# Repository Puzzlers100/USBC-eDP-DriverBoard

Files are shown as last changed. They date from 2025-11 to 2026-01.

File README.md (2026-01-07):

## __USBC-eDP Driver Board__  

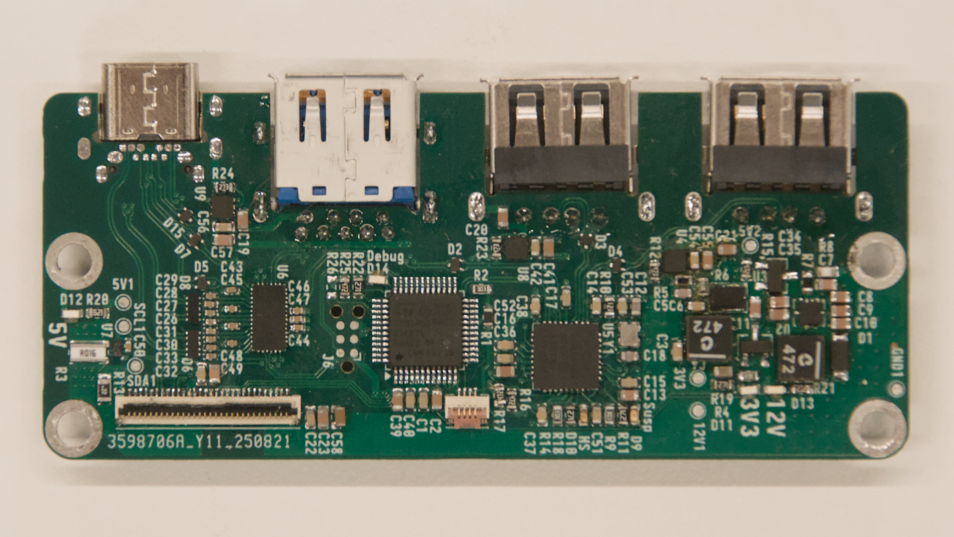
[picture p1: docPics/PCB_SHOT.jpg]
Soldered embedded displayport adapter

This project works to adapt a USB-C DisplayPort alt-mode input into an embedded DisplayPort output. It uses an STM32 to communicate over the USB-C Power delivery protocol, acts as a USB Hub providing one USB 3.0 Superspeed port and 2 USB 2.0 High Speed ports. It also negotiates the highest current available from the source, and internally generates the 12V needed to run the display.  It works by simply routing the same DP signals through to the output, and does no signal processing of it's own. 
## USE  

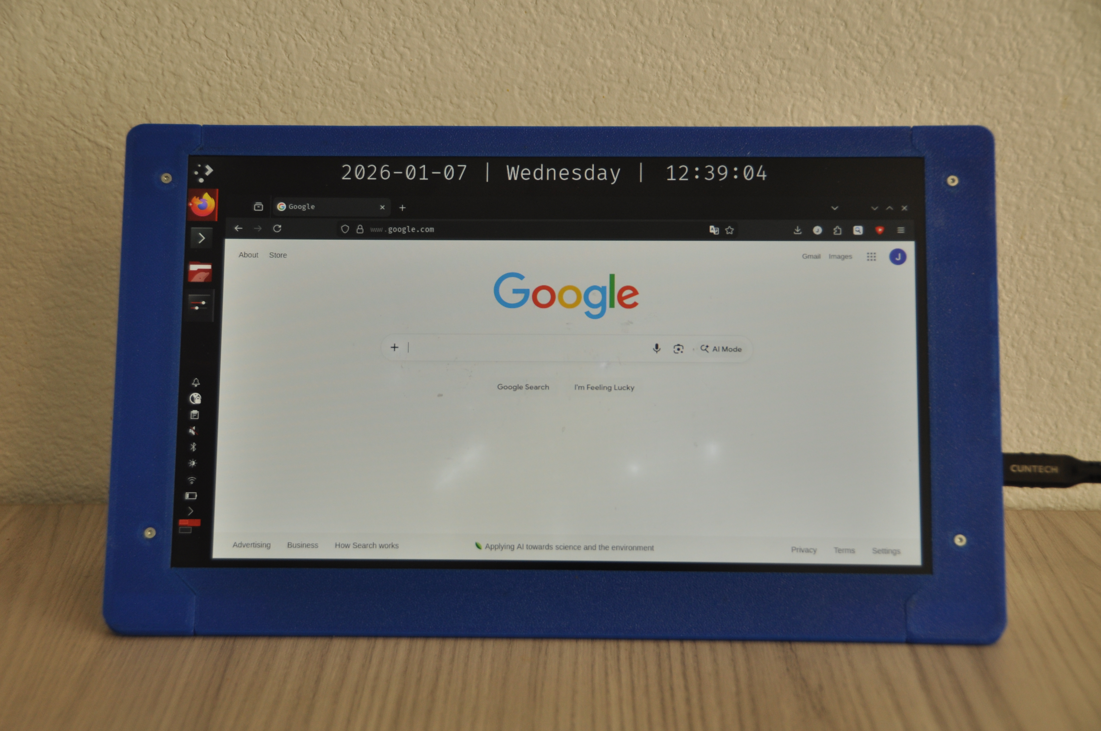
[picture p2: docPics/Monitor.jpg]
Portable monitor built using this driver board


It should work with most 30pin eDP panels. Since it has no native processing on it's own, the DP generation is set by the computer and panel used. Generally, this allows for up to 1080p panels. Exceptionally large or exceptionally bright panels may not work, as those panels tend to draw a large current on the 12V rail. I highly recommend sticking to panels that draw a continuous current of no more than 800mA for the backlight.

The STM32 provides PWM dimming capability by using the potentiometer on the daughter board. If you want to remove this capability, short pin 1 to pin 2 on J2 (This is a temporary solution, the plan is to in the future specify which brightness control scheme should be used using R25 and R26)

Personally, I am using the Innolux N116BCA-EA1 panel with a 3D printed case published in the Mechanical folder. If you would prefer a 1080p panel, the AUO G116HAN looks like it should also fit the case, however I do not have one to test with. 

#### NOTICE
The USB 2.0 ports are configured to run outside of the USB specification. They claim to be able to provide up to 500mA of current, however trigger overcurrent protection at 250mA. This can be fixed by replacing line 17 in i2C_comms.c with {0x18, 0x20, 0x01}, however the incorrect version can be useful with higher power flash drives that require 200mA, which was the reason I chose to do it this way.
## BUILD INFO

#### PCBs
BOMs for both the main board and secondary board are in the electrical folder, and contain all the parts required to build a fully functional PCB.  The main board is specifically designed to be manufactured using JLC-PCBs JLC04081H-3313 stackup, as the USB lines are impedance matched, and the generated gerber files are designed to be used with JLC. The potentiometer board has no such restrictions, but I recommend using a 0.8mm PCB. Currently there is no pick and place support, so you will need to hand solder the PCBs. The passives should be rated for at least 12V

## Firmware
The firmware is written using the STMCube Ide. To get the PCB to work, you need to compile it using cube IDE, then upload it to the STM32 using either a J-link or STlink. If you have a TagConnect TC2030, there is a pad connector available on the PCB, if not, the pads are big enough you could solder on some leads to them.

## FFC cables
The design uses a Type A, 4pin, 0.5mm pitch FFC cable to connect the main board and pot board. For my design, I used a 10cm long cable, though what length you need may depend on your chosen LCD and layout

You will also require a 30 pin eDP cable. I used a 250mm one for my design.

## Hardware
The mechanical design is published as a set of solidworks files as well as a set of 3MFs. The 3MFs were made for the Prusa MK3S+ with the MMU2, though they will likely work with most slicers and printers that support multi filament printing. They are designed to be printed in PETG with appropriate scaling to account for shrinkage. A couple of the parts also have support blocks with a PLA interface so they should be removable. 

To fully assemble the enclosure, you will need:

- 19x [M2 4.8mm Wide, 1.5mm thick nuts](https://www.mcmaster.com/92513A110/)
- 13x [M2 10mm Countersunk Screw](https://www.mcmaster.com/90236A106/)
- 17x [M2 6mm Countersunk Screw](https://www.mcmaster.com/90236A104/)
- 13x [M2 4mm Countersunk Screw](https://www.mcmaster.com/90236A102/) 
	
## TODO
Future Plans are mostly in the software:
 - USB HID interface for brightness control and notifications
 - Proper current monitoring and active over-current protection control by reducing screen brightness
 - Use R25 and R26 resistors to define which brightness control method is desired.
 - Redesign the enclosure to use metal nuts. I just used some nuts I had on hand that I thought were M2 but are actually probably M2.5

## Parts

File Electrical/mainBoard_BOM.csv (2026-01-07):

Id | Designator | Footprint | Quantity | Designation | Manufacturer | Ref
1 | C1,C39,C38,C16,C51,C55,C14,C41,C17,C52,C24,C53,C57,C6,C22,C37,C15 | 0603_C | 17 | 100n
2 | C25,C11,C54,C23,C35,C42,C2,C56,C8,C13,C19,C21,C9,C36,C7,C40,C34,C10,C20 | 0603_C | 19 | 10u
3 | J2 | FH19C-4S-0.5SH(10) | 1 | 4_Pin_Zif | Hirose | FH19C-4S-0.5SH(10)
4 | Q2 | TSOT-23 | 1 | NPN | onsemi | NSS40201LT1G
5 | R9,R6,R4,R14 | 0603_R | 4 | 30K
6 | D13,D12,D9,D11,D10,D14 | LTST_Diode | 6 | LED | LITE-ON | S270GTK
7 | C44,C47,C43,C50,C46,C45,C49,C48 | 0402_C | 8 | 100n
8 | C58 | 0603_C | 1 | 22u
9 | R5 | 0603_R | 1 | 91K
10 | R1 | 0603_R | 1 | 200K
11 | L2,L1 | XGL4018_Inductor | 2 | 4.7uH | Coilcraft | XGL4018
12 | R13 | 0805_R | 1 | 0
13 | Q1 | TSOT-23 | 1 | PMOS | Vishay | SQ2303CES-T1_BE3
14 | R17,R16,R25,R26,R15 | 0603_R | 5 | 4K7
15 | U4,U8,U9 | AP22652-DFN | 3 | AP22653 | Diodes Inc | AP22653FDZ-7
16 | R7 | 0603_R | 1 | 20K
17 | U6 | TMUXHS4446 | 1 | TMUXHS4446 | Texas Instruments | TMUXHS4446RETR
18 | R2 | 0603_R | 1 | 40K2
19 | U7 | INA234 | 1 | INA234AxYBJ | Texas Instruments | INA234AIYBJR
20 | D7,D3,D15,D2,D5,D4 | ESD7L5 | 6 | ESD7L5 | onsemi | ESD7L5.0DT5G
21 | R12,R23 | 0603_R | 2 | 47K
22 | C32,C31,C28,C26,C27,C30,C29,C33 | 0402_C | 8 | 220n
23 | C4,C3 | 0603_C | 2 | 22uF
24 | R11,R22,R18,R19 | 0603_R | 4 | 270
25 | D8,D6 | ESD7004 | 2 | ESD7004 | onsemi | ESD7004MUTAG
26 | J1 | FH19SC-30S-0.5SH(09) | 1 | 30_Pin_Zif | hirose | FH19SC-30S-0.5SH(09)
27 | U1 | LQFP-48_7x7mm_P0.5mm | 1 | STM32G0B1CETx | ST Micro | STM32G0B1CET6
28 | R10 | 0603_R | 1 | 12K1%
29 | R21 | 0603_R | 1 | 2K
30 | D1 | SS3020HE | 1 | SS3020HE | Panjit international | SS3020HE_R1_00001
31 | Y1 | FA-128_OSC | 1 | 24MHz | EPSON | FA-128 24.0000MF10Z-W0
32 | C12,C18 | 0603_C | 2 | 18pF
33 | R8 | 0603_R | 1 | 180K
34 | C5 | 0603_C | 1 | 33pF
35 | U2 | MCP1665 | 1 | MCP1665 | Microchip | MCP1665T-E/MRA
36 | U5 | USB2514v2 | 1 | USB2514B | Microchip | USB2514B/M2
37 | U3 | AP63357 | 1 | AP63357 | Diodes Inc | AP63357DV-7
38 | R20 | 0603_R | 1 | 620
39 | R3 | 0612_R_v2 | 1 | 16m | YAGEO | PE0612FKF070R016L
40 | R24 | 0603_R | 1 | 27K
41 | J3 | USBA32_692121230100v2_1.6mmOut | 1 | USB3_A | Wurth Elektronik | 692121230100
42 | J7 | 2129691-2_2.8mmOut | 1 | 2129691-2 | TE Connectivity | 2129691-2
43 | J5,J4 | USB1015v2_1.6mmOut | 2 | USB_A | GCT | USB1015-GF-L-A
44 | M4,M2,M3,M1 | MS04-M2-2 | 4 | Standoff | PEM | MSO4-M2-2

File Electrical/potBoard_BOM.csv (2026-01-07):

Id | Designator | Footprint | Quantity | Designation | Manufacturer | Ref
1 | R1 | RK10J12R0A0B | 1 | 10k | Alps Alpine | RK10J12R0A0B
2 | J1 | FH19C-4S-0.5SH(10) | 1 | Conn_01x05 | Hirose | FH19C-4S-0.5SH(10)
3 | M1,M2,M3 | MS04-M2-2 | 3 | Standoff | PEM | MSO4-M2-2

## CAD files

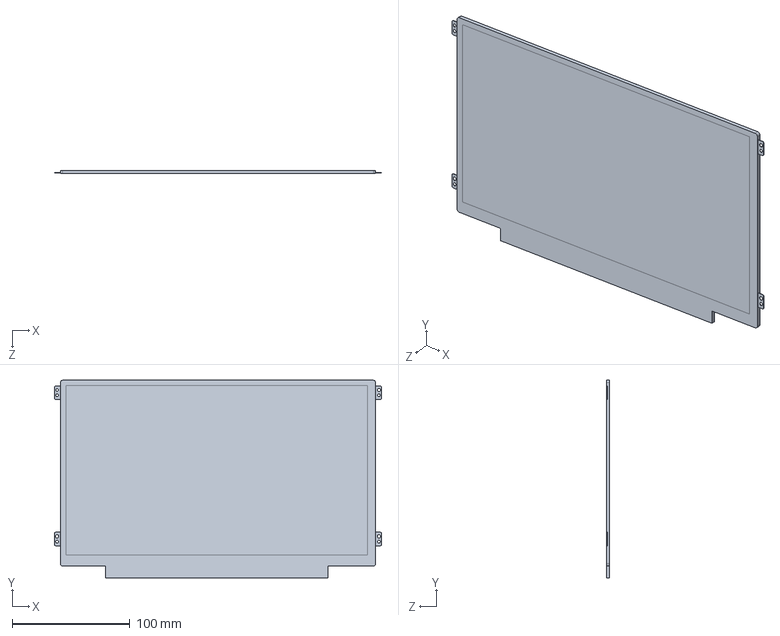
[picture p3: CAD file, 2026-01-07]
Mechanical/N116BCA-EA1.SLDPRT
278.0 x 168.0 x 2.90 mm

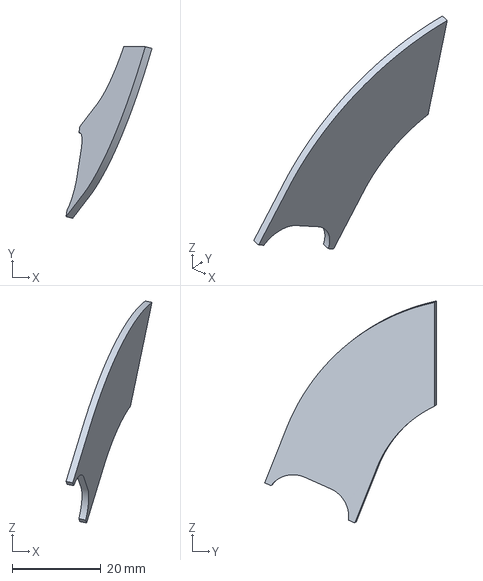
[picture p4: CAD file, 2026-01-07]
Mechanical/Print/support_DO_NOT_PRINT.3MF
19.3 x 38.6 x 49.9 mm

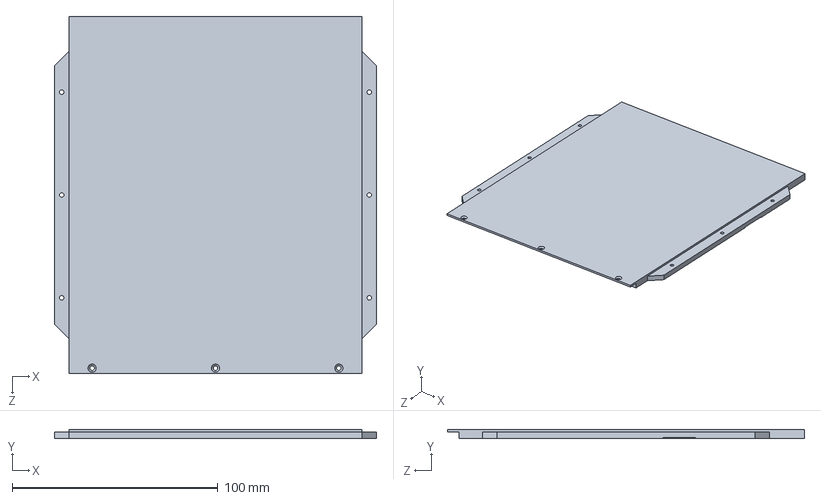
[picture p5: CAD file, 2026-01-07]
Mechanical/Back.SLDPRT
156.8 x 4.40 x 173.6 mm

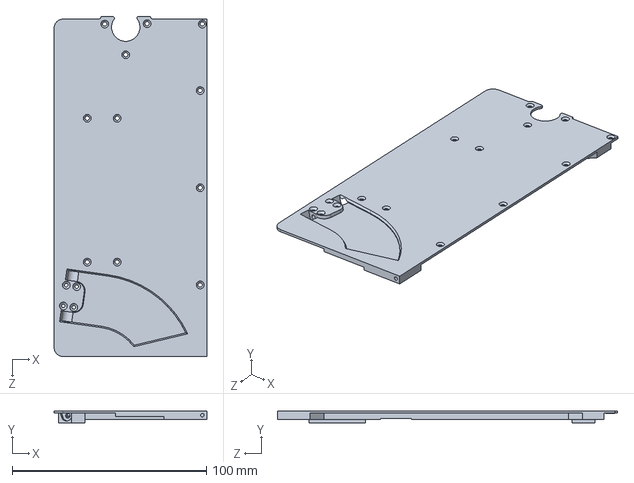
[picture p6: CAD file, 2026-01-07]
Mechanical/Right_Back_ROTFIX.SLDPRT
78.7 x 6.30 x 174.9 mm

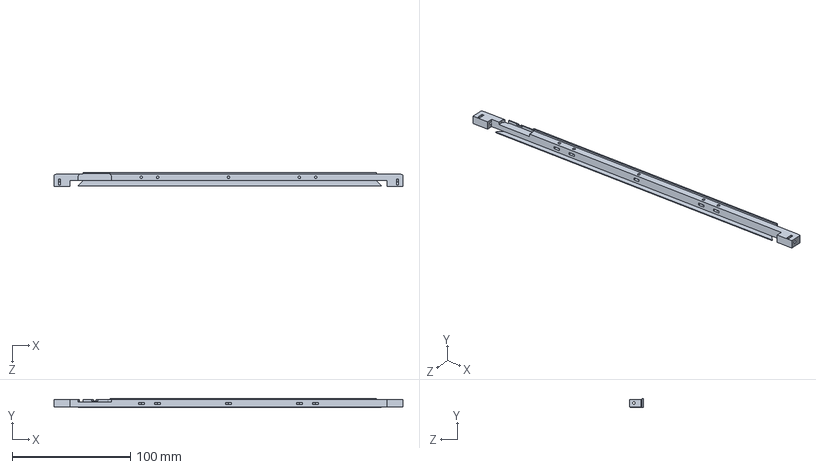
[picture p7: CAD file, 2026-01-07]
Mechanical/Top_Bezel.SLDPRT
295.2 x 8.00 x 11.6 mm

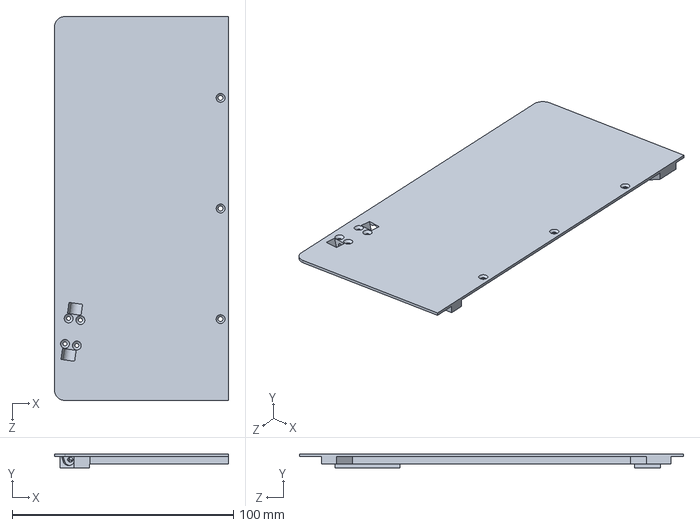
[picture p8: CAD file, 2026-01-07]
Mechanical/Left_Back.SLDPRT
78.7 x 6.30 x 173.6 mm

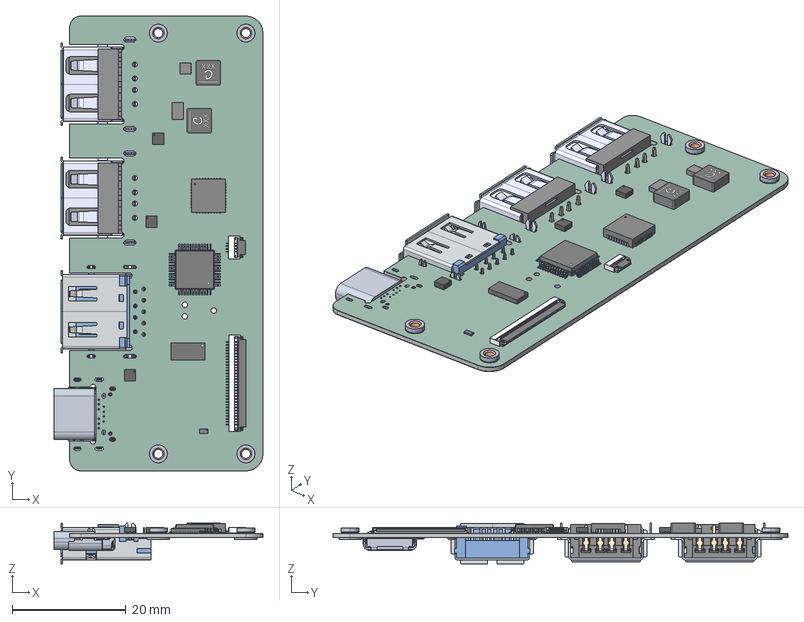
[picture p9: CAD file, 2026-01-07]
Mechanical/DisplayAdapter_SIMPLE.step
36.8 x 80.0 x 7.16 mm
FH19C-4S-0.5SH_Èª
kicad_embedded_4BD10C742DC7AB2F1A7572D055C19346 x 2
kicad_embedded_8E2257DE73F7A6E4D194A23885C88B5F
FH19SC-30S-0.5SH_Èª
LQFP-48_7x7mm_P0.5mm
kicad_embedded_60FAC7AAB89A76125E2CAA4BB967ED54
kicad_embedded_AC5888F7A4D657B370E01069BEED499E
kicad_embedded_53DF632D9B4F967877471FEA8CA58016
pin2 x 4
pin x 5
Housing1
Housing2
Shielding
kicad_embedded_1FC57DCAA98C58E4B17815415C89B4E5
kicad_embedded_95AC69201238B84520BACC3332528FB5 x 2
kicad_embedded_837B63221ABB4DC24071B6AB66149768 x 4
DisplayAdapter_soldermask
DisplayAdapter_PCB

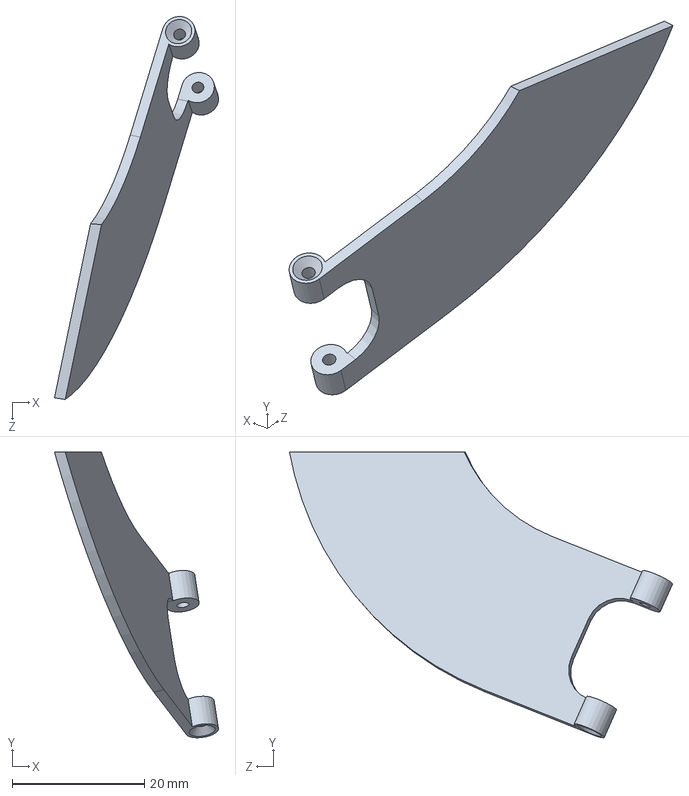
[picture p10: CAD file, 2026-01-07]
Mechanical/Left_Stand.SLDPRT
24.8 x 43.1 x 57.8 mm

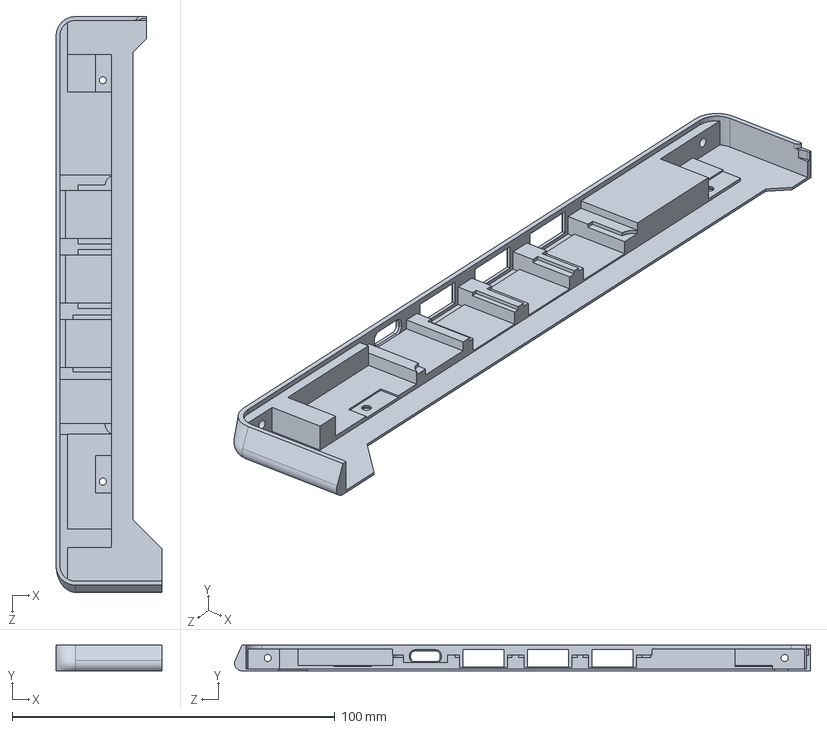
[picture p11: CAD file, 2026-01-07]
Mechanical/Right_Bezel.SLDPRT
32.8 x 8.00 x 178.5 mm

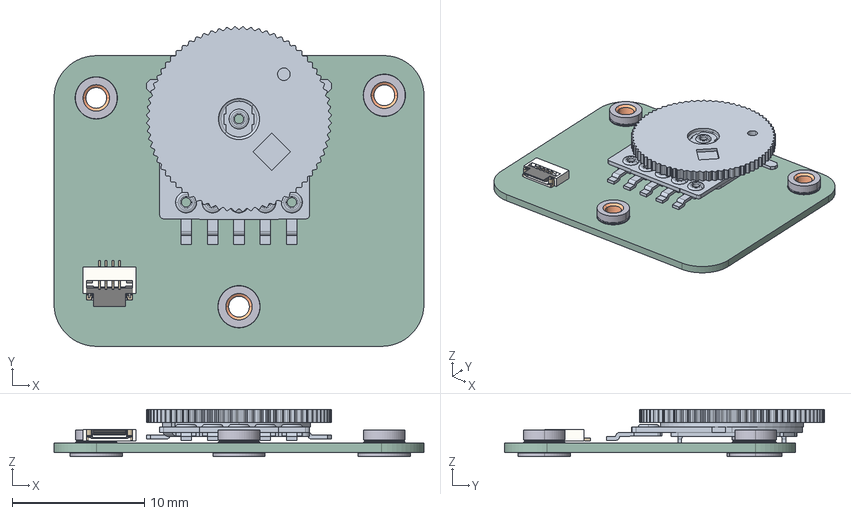
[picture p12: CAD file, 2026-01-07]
Mechanical/eDP_Adapter_potBoard_simplified.step
28.0 x 24.2 x 3.58 mm
eDP_Adapter_potBoard_simplified 1.1
FH19C-4S-0.5SH_Èª
kicad_embedded_837B63221ABB4DC24071B6AB66149768 x 3
eDP_Adapter_potBoard_PCB

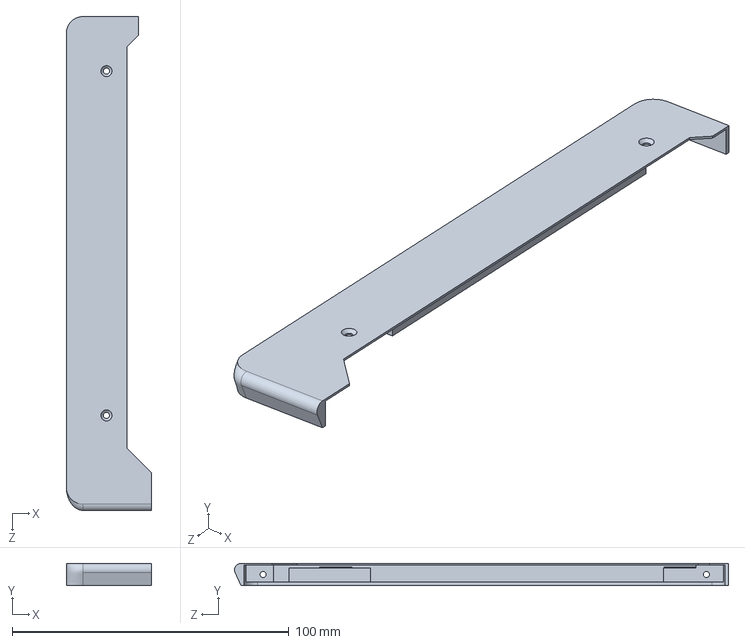
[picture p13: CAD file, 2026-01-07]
Mechanical/Left_Bezel.SLDPRT
30.8 x 8.00 x 178.5 mm

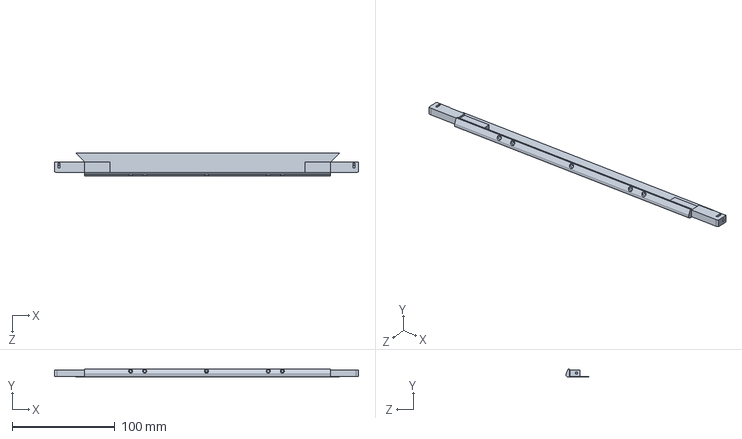
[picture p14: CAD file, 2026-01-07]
Mechanical/Bot_Bezel.SLDPRT
295.2 x 8.00 x 22.6 mm

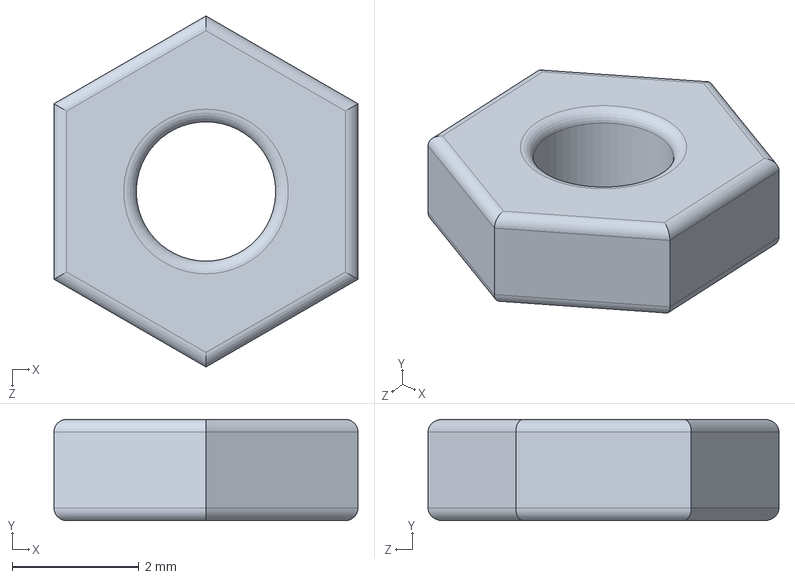
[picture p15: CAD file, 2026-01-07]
Mechanical/M2_nut.SLDPRT
4.80 x 1.60 x 5.54 mm

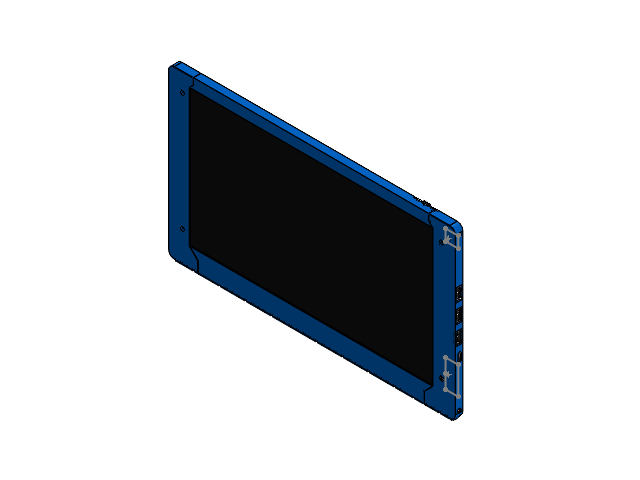
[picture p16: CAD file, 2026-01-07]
Mechanical/LCD_ASM_V3.SLDASM
N116BCA-EA1
Right_Bezel
Left_Bezel
Top_Bezel
Bot_Bezel
90236A106_Zinc-Plated Steel Torx Flat Head Screws x 5
Right_Stand
90236A104_Zinc-Plated Steel Torx Flat Head Screws x 5
M2_nut
Right_Back_ROTFIX
Left_Back_ROTFIX
Left_Stand
Back
FH19C-4S-0.5SH_________.step
Body002.step x 18
Body.step x 3
Body001.step x 3
Body003.step x 3
Sphere.step x 8
Body-0.step
Body001-1.step
FH19SC-30S-0.5SH_________.step
pin2.step x 4
pin.step x 5
Housing1.step
Housing2.step
Shielding.step
kicad_embedded_4BD10C742DC7AB2F1A7572D055C19346.step x 2
kicad_embedded_8E2257DE73F7A6E4D194A23885C88B5F.step
LQFP-48_7x7mm_P0.5mm.step
kicad_embedded_60FAC7AAB89A76125E2CAA4BB967ED54.step
kicad_embedded_AC5888F7A4D657B370E01069BEED499E.step
kicad_embedded_53DF632D9B4F967877471FEA8CA58016.step
kicad_embedded_1FC57DCAA98C58E4B17815415C89B4E5.step
kicad_embedded_95AC69201238B84520BACC3332528FB5.step x 2
kicad_embedded_837B63221ABB4DC24071B6AB66149768.step x 4
DisplayAdapter_soldermask.step
DisplayAdapter_PCB.step
FH19C-4S-0.5SH__________1.step
eDP_Adapter_potBoard_simplified 1.1.step
kicad_embedded_837B63221ABB4DC24071B6AB66149768_1.step x 3
eDP_Adapter_potBoard_PCB.step

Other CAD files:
Mechanical/support.SLDPRT
Mechanical/Left_Back_ROTFIX.SLDPRT
Mechanical/Right_Stand.SLDPRT
Mechanical/Print/Back.3MF
Mechanical/Print/Bot_Bezel.3MF
Mechanical/Print/Left_Back_ROTFIX.3MF
Mechanical/Print/Left_Bezel.3MF
Mechanical/Print/Left_Stand.3MF
Mechanical/Print/Right_Back_ROTFIX.3MF
Mechanical/Print/Right_Bezel.3MF
Mechanical/Print/Right_Stand.3MF
Mechanical/Print/Top_Bezel.3MF

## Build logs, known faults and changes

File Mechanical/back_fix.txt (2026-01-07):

"LCD_Height"= 158mm

"LCD_Width"= 268mm

"LCD_PCB_Height"= 10mm

"LCD_PCB_Width"= 189

"LCD_PCB_LOff"= 38.5

"LCD_Thick"= 2.9mm

"LCD_TBezel"= 4.6mm

"LCD_LBezel"= 4.94mm

"LCD_RBezel"= 6.94mm

"LCD_BBezel"= 9.4mm

"Wing_Height"= 11.5mm

"Wing_Width"= 5mm

"Wing_Corner"= 1mm

"Wing_Hole_VOff"= 3.5mm

"Wing_Hole_HOff"= 2.8mm

"Wing_Spacing"= 128.9 + 2 * "Wing_Hole_VOff" - "Wing_Height"

"Wing_TOff"= 8.35 - "Wing_Hole_VOff"

"Wing_DOff"= 0.7mm

"Wing_Thick"= 0.3mm

"Print_Gap"= 0.2mm

"Pin1_Pos"= 89.75mm

"Pin_Space"= 0.5mm

"Pin_num"= 30

"Min_Thick"= 1.2mm

"Nut_Width"= 4.8mm

"Nut_Height"= 5.6mm

"Nut_Thick"= 1.6mm

"Screw_Hole"= 2.2mm

"Screw_Chamf"= 0.9mm

"Bezel_Gap"= 0.4mm

"USB_Width"= 16mm

"Corner_Radius"= 6mm

"D2@Sketch1"="LCD_Height" + "LCD_PCB_Height" + "Print_Gap" + 2 * "Min_Thick" + "Nut_Height"

"D3@Sketch1"="Print_Gap" / 2 + "Min_Thick"

"D4@Sketch1"="Min_Thick" + "Print_Gap" / 2

"D5@Sketch1"="Corner_Radius"

"D1@Boss-Extrude1"="Min_Thick"

"D6@Sketch1"="Print_Gap" / 2 + "Min_Thick"

"D1@Sketch4"="LCD_Height"

"D1@Boss-Extrude3"=8 - "Min_Thick" - 0.6 - "Print_Gap" / 2 - "LCD_Thick"

"D3@Sketch4"="Min_Thick" + "Print_Gap" / 2 + "USB_Width"

"D1@Sketch6"=3 * "Min_Thick" + "Print_Gap" / 2

"D2@Sketch6"="Nut_Width" + 2 * "Min_Thick" + 22

"D3@Sketch6"= "Min_Thick" + "USB_Width"

"D4@Sketch6"="Wing_Spacing"

"D5@Sketch6"="Min_Thick" + "Nut_Height" + "Print_Gap"/2 + "Wing_TOff" + "Wing_Height" - "Wing_Hole_VOff"

"D6@Sketch6"="Wing_Hole_HOff"

"D7@Sketch6"="Screw_Hole"

"D8@Sketch6"="Wing_Hole_HOff"

"D9@Sketch6"="Nut_Width" / 2 + "Min_Thick"

"D10@Sketch6"= "Screw_Chamf" + "Screw_Hole" / 2 + "Min_Thick" + "Nut_Width" / 2 + "Print_Gap" / 2

"D1@Boss-Extrude4"= 8 - 0.6 - "Min_Thick" - "Wing_DOff" - "Print_Gap"/2 - "Wing_Thick"

"D2@Sketch4"="Min_Thick" + "Nut_Height" + "Print_Gap" / 2

"Stand_Tilt"= 8

"Screen_Tilt"= 24

"Stand_Splay"= 16

"D1@Sketch9"=2 * 1.6 + 1.8 + 2 * "Print_Gap" 

"D3@Sketch9"="Stand_Tilt"

"D4@Sketch9"=2.7 * tan("Stand_Splay") + "Min_Thick" / 2

"D6@Sketch9"="Min_Thick" / 2

"D1@Sketch11"="Screw_Hole" + "Print_Gap"

"D1@Sketch15"="Stand_Splay"

"D1@Sketch20"="Nut_Width"  + "Min_Thick"

"D2@Sketch20"= 0.5 * "Nut_Height"

"D1@Cut-Extrude10"="Nut_Thick" + "Print_Gap" + "Min_Thick" * 1.5

"D1@Sketch22"="Nut_Width" + "Print_Gap"

"D1@Cut-Extrude12" = "Nut_Thick" + "Print_Gap"

"D3@Sketch24"= 1.8 + 2.4 + "Min_Thick"

"D4@Sketch24"=2 + .6

"D5@Sketch24"=2 + .6

"D1@Chamfer1"= "Print_Gap" + "Screw_Chamf"

"D1@Sketch28"="Nut_Width" + "Print_Gap"

"D2@Sketch28"="Nut_Height" + "Min_Thick"

"D1@Cut-Extrude17"="Nut_Thick" + "Print_Gap"

"D4@Sketch31"="Nut_Width" + 2 * "Min_Thick"

"D1@Sketch32"="Screw_Hole"

"D3@Sketch32"="Nut_Width" / 2 + "Min_Thick"

"D1@Chamfer2"="Screw_Chamf"

"D4@Sketch33"=16 + 2 * "Print_Gap"

"D5@Sketch33"="Print_Gap"

"D2@Sketch34"="Min_Thick" + "USB_Width" + "Print_Gap" / 2 +"LCD_RBezel" - "Bezel_Gap"

"D3@Sketch34"="Min_Thick" + "Print_Gap" / 2 +"LCD_PCB_Height"

"D4@Sketch34"="LCD_BBezel" - "Bezel_Gap"

"D5@Sketch34"="Print_Gap" / 2

"D1@Sketch35"="Min_Thick" + "USB_Width" +"Print_Gap" / 2 + "LCD_Width" - "LCD_PCB_LOff" - "LCD_PCB_Width"

"D1@Sketch44"="Screw_Hole" - 2 * "Print_Gap"

"D2@Sketch44"="Nut_Width" / 2

"D1@Sketch45"="Min_Thick" + "Nut_Height" / 2 - "Print_Gap" / 2

"D2@Sketch45"="Nut_Width" / 2

"D3@Sketch45"="Screw_Hole"

"D1@Chamfer3"="Screw_Chamf"

"D2@Sketch50"="Print_Gap"

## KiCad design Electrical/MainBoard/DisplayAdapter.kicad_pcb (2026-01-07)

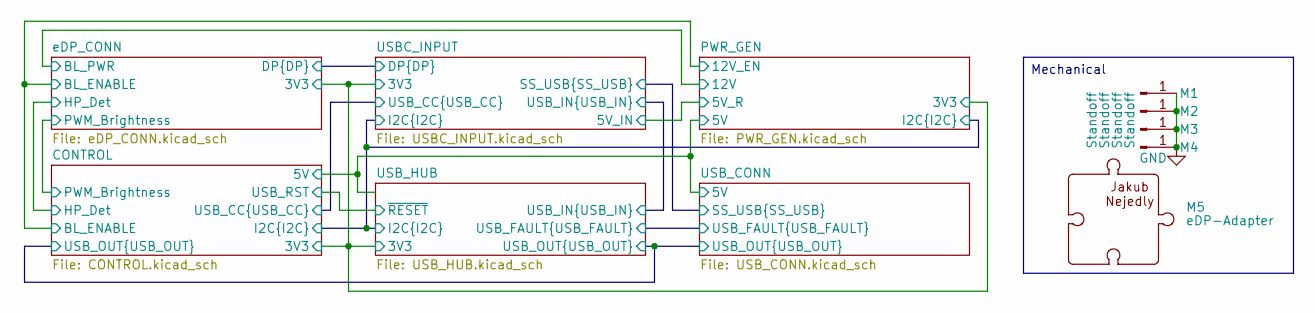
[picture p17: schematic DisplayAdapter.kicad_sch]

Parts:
M1, M2, M3, M4: Standoff; MS04-M2-2
M5: eDP-Adapter; Logo

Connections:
GND: M1.1, M2.1, M3.1, M4.1; also elsewhere on the board

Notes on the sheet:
Mechanical

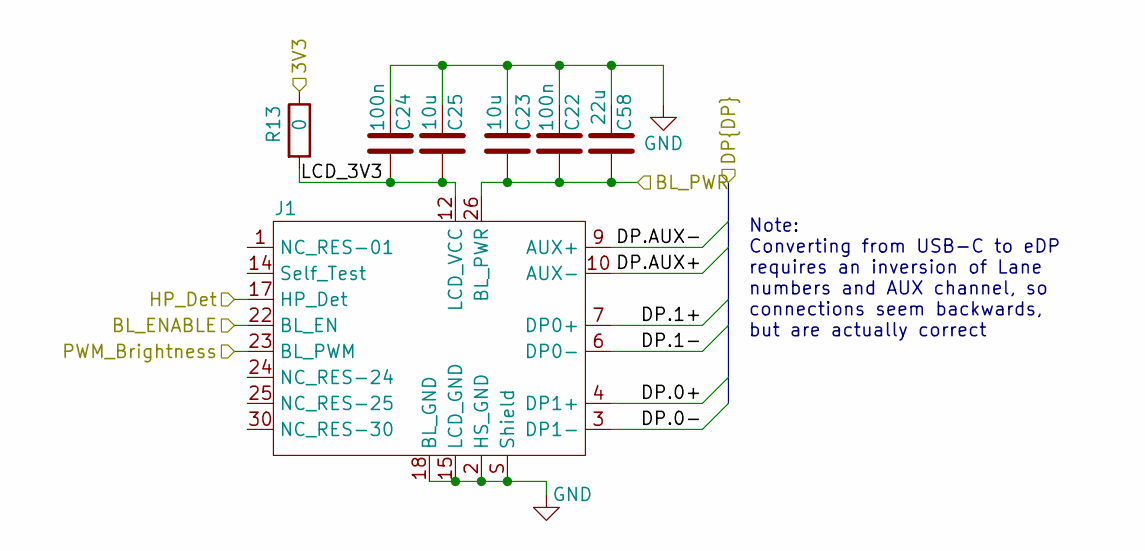
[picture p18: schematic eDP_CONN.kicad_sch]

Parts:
C22, C24: 100n; 0603_C
C23, C25: 10u; 0603_C
C58: 22u; 0603_C
J1: 30_Pin_Zif; FH19SC-30S-0.5SH(09)
R13: 0; 0805_R

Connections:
/CONTROL/3V3: R13.1; also elsewhere on the board
/CONTROL/BL_ENABLE: J1.22 (BL_EN); also elsewhere on the board
/CONTROL/HP_Det: J1.17 (HP_Det); also elsewhere on the board
/CONTROL/PWM_Brightness: J1.23 (BL_PWM); also elsewhere on the board
/PWR_GEN/12V: C22.2, C23.2, C58.2, J1.26 (BL_PWR), J1.27 (BL_PWR), J1.28 (BL_PWR), J1.29 (BL_PWR); also elsewhere on the board
/USBC_INPUT/DP.0+: J1.4 (DP1+); also elsewhere on the board
/USBC_INPUT/DP.0-: J1.3 (DP1-); also elsewhere on the board
/USBC_INPUT/DP.1+: J1.7 (DP0+); also elsewhere on the board
/USBC_INPUT/DP.1-: J1.6 (DP0-); also elsewhere on the board
/USBC_INPUT/DP.AUX+: J1.10 (AUX-); also elsewhere on the board
/USBC_INPUT/DP.AUX-: J1.9 (AUX+); also elsewhere on the board
/eDP_CONN/LCD_3V3: C24.1, C25.1, J1.12 (LCD_VCC), J1.13 (LCD_VCC), R13.2
GND: C22.1, C23.1, C24.2, C25.2, C58.1, J1.2 (HS_GND), J1.5 (HS_GND), J1.8 (HS_GND), J1.11 (HS_GND), J1.15 (LCD_GND), J1.16 (LCD_GND), J1.18 (BL_GND), J1.19 (BL_GND), J1.20 (BL_GND), J1.21 (BL_GND), J1.S (Shield); also elsewhere on the board

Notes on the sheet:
Note: Converting from USB-C to eDP requires an inversion of Lane numbers and AUX channel, so connections seem backwards, but are actually correct

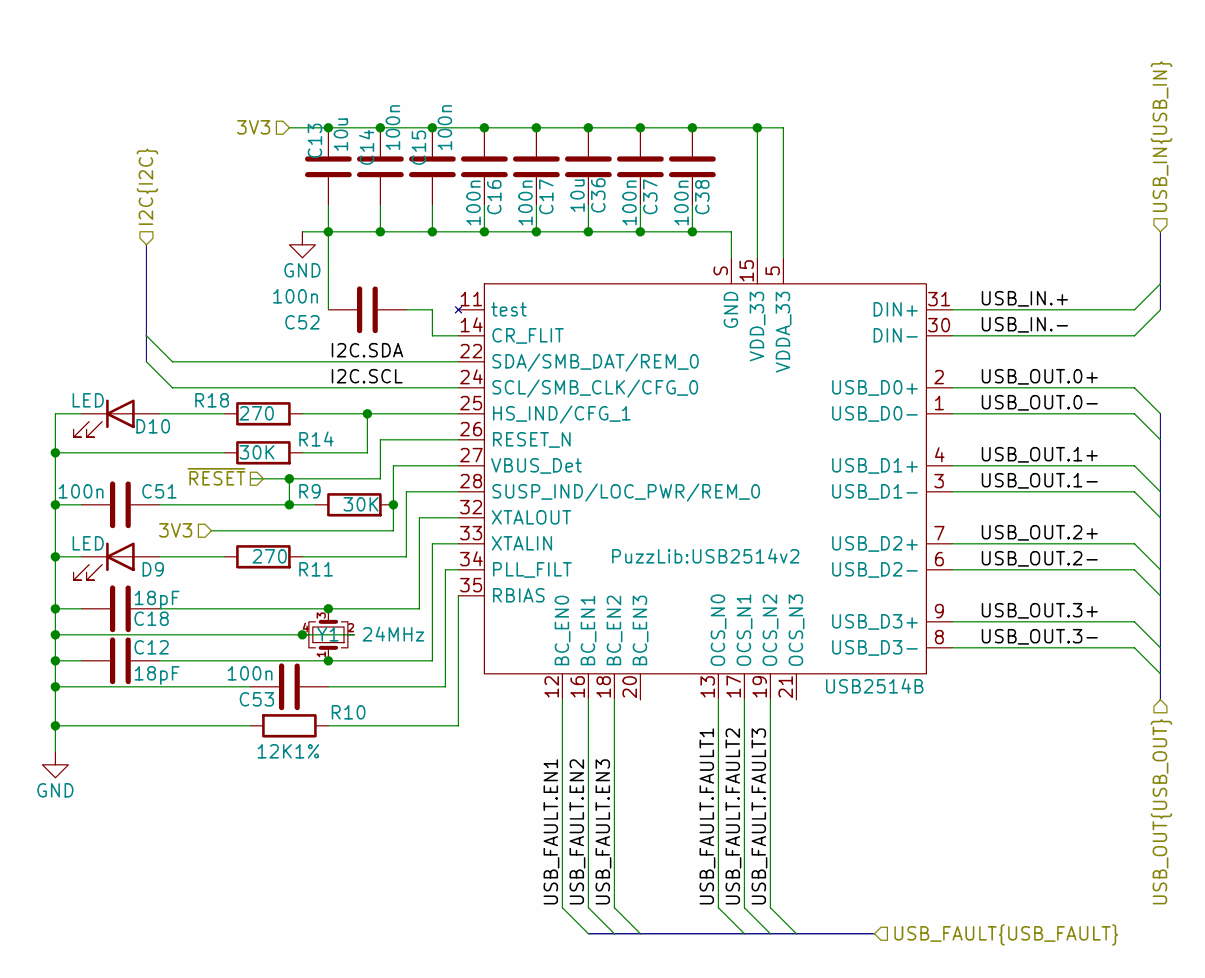
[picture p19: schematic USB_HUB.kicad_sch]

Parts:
C12, C18: 18pF; 0603_C
C13, C36: 10u; 0603_C
C14, C15, C16, C17, C37, C38, C51, C52, C53: 100n; 0603_C
D9, D10: LED; LTST_Diode
R9, R14: 30K; 0603_R
R10: 12K1%; 0603_R
R11, R18: 270; 0603_R
U5: USB2514B; USB2514v2
Y1: 24MHz; FA-128_OSC

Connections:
/CONTROL/3V3: C13.2, C14.2, C15.2, C16.2, C17.2, C36.2, C37.2, C38.2, R9.2, U5.5 (VDDA_33), U5.10 (VDDA_33), U5.15 (VDD_33), U5.23 (VDD_33), U5.27 (VBUS_Det), U5.29 (VDDA_33), U5.36 (VDDA_33); also elsewhere on the board
/CONTROL/I2C.SCL: U5.24 (SCL/SMB_CLK/CFG_0); also elsewhere on the board
/CONTROL/I2C.SDA: U5.22 (SDA/SMB_DAT/REM_0); also elsewhere on the board
/CONTROL/USB_OUT.0+: U5.2 (USB_D0+); also elsewhere on the board
/CONTROL/USB_OUT.0-: U5.1 (USB_D0-); also elsewhere on the board
/CONTROL/USB_OUT.1+: U5.4 (USB_D1+); also elsewhere on the board
/CONTROL/USB_OUT.1-: U5.3 (USB_D1-); also elsewhere on the board
/CONTROL/USB_OUT.2+: U5.7 (USB_D2+); also elsewhere on the board
/CONTROL/USB_OUT.2-: U5.6 (USB_D2-); also elsewhere on the board
/CONTROL/USB_OUT.3+: U5.9 (USB_D3+); also elsewhere on the board
/CONTROL/USB_OUT.3-: U5.8 (USB_D3-); also elsewhere on the board
/CONTROL/USB_RST: C51.1, R9.1, U5.26 (RESET_N); also elsewhere on the board
/USBC_INPUT/USB_IN.+: U5.31 (DIN+); also elsewhere on the board
/USBC_INPUT/USB_IN.-: U5.30 (DIN-); also elsewhere on the board
/USB_CONN/USB_FAULT.EN1: U5.12 (BC_EN0); also elsewhere on the board
/USB_CONN/USB_FAULT.EN2: U5.16 (BC_EN1); also elsewhere on the board
/USB_CONN/USB_FAULT.EN3: U5.18 (BC_EN2); also elsewhere on the board
/USB_CONN/USB_FAULT.FAULT1: U5.13 (OCS_N0); also elsewhere on the board
/USB_CONN/USB_FAULT.FAULT2: U5.17 (OCS_N1); also elsewhere on the board
/USB_CONN/USB_FAULT.FAULT3: U5.19 (OCS_N2); also elsewhere on the board
GND: C12.2, C13.1, C14.1, C15.1, C16.1, C17.1, C18.2, C36.1, C37.1, C38.1, C51.2, C52.2, C53.2, D9.1 (K), D10.1 (K), R10.2, R14.1, U5.S (GND), Y1.2, Y1.4; also elsewhere on the board
unnamed: D9.2 (A), R11.1
unnamed: D10.2 (A), R18.1
unnamed: C52.1, U5.14 (CR_FLIT)
unnamed: R14.2, R18.2, U5.25 (HS_IND/CFG_1)
unnamed: C53.1, U5.34 (PLL_FILT)
unnamed: R10.1, U5.35 (RBIAS)
unnamed: R11.2, U5.28 (SUSP_IND/LOC_PWR/REM_0)
unnamed: C12.1, U5.33 (XTALIN), Y1.1
unnamed: C18.1, U5.32 (XTALOUT), Y1.3

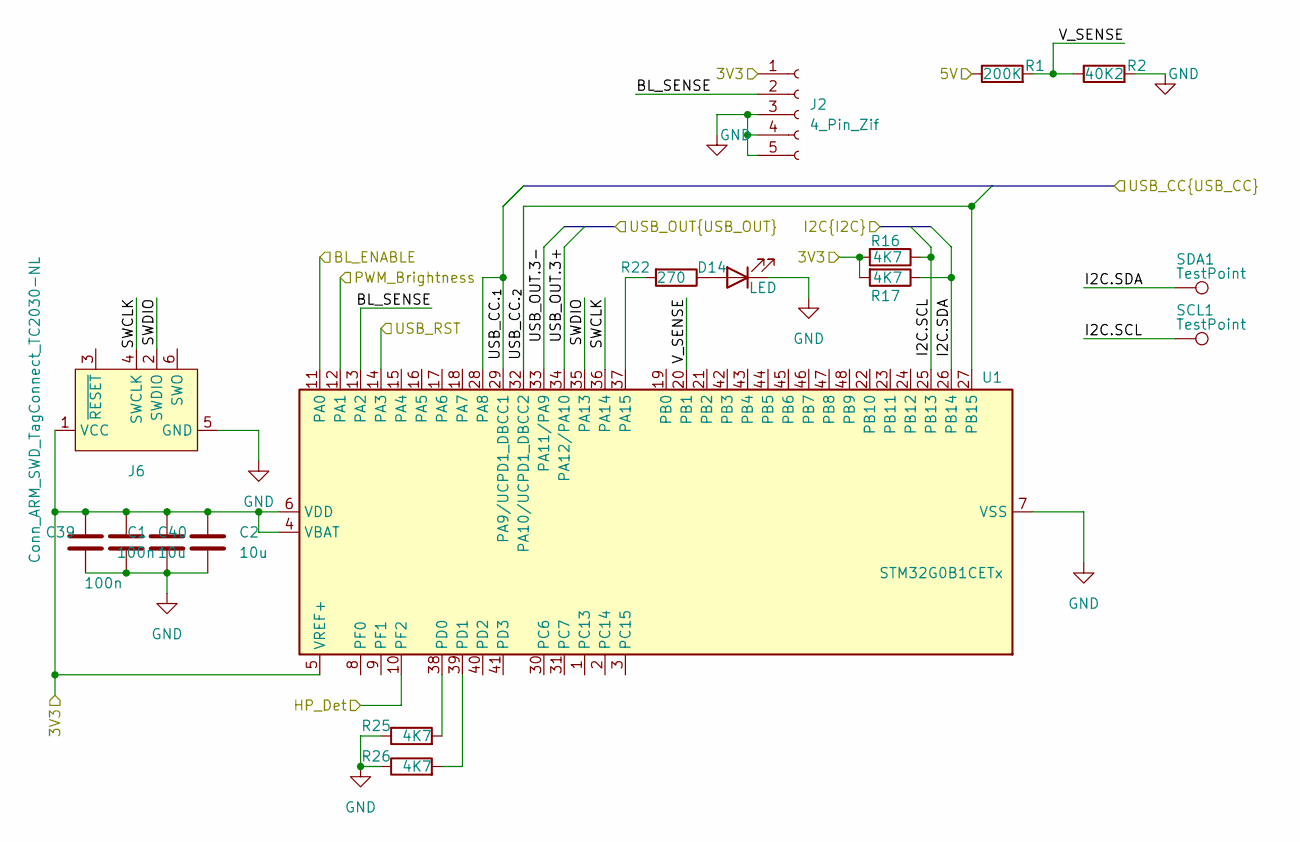
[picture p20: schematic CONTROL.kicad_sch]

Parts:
C1, C39: 100n; 0603_C
C2, C40: 10u; 0603_C
D14: LED; LTST_Diode
J2: 4_Pin_Zif; FH19C-4S-0.5SH(10)
J6: Conn_ARM_SWD_TagConnect_TC2030-NL; Tag-Connect_TC2030-IDC-NL_2x03_P1.27mm_Vertical
R1: 200K; 0603_R
R2: 40K2; 0603_R
R16, R17, R25, R26: 4K7; 0603_R
R22: 270; 0603_R
SCL1: TestPoint; TestPoint_Pad_D1.0mm
SDA1: TestPoint; TestPoint_Pad_D1.0mm
U1: STM32G0B1CETx; LQFP-48_7x7mm_P0.5mm

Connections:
/CONTROL/3V3: C1.1, C2.1, C39.1, C40.1, J2.1, J6.1 (VCC), R16.2, R17.2, U1.4 (VBAT), U1.5 (VREF+), U1.6 (VDD); also elsewhere on the board
/CONTROL/BL_ENABLE: U1.11 (PA0); also elsewhere on the board
/CONTROL/BL_SENSE: J2.2, U1.13 (PA2)
/CONTROL/HP_Det: U1.10 (PF2); also elsewhere on the board
/CONTROL/I2C.SCL: R16.1, SCL1.1, U1.25 (PB13); also elsewhere on the board
/CONTROL/I2C.SDA: R17.1, SDA1.1, U1.26 (PB14); also elsewhere on the board
/CONTROL/PWM_Brightness: U1.12 (PA1); also elsewhere on the board
/CONTROL/SWCLK: J6.4 (SWCLK), U1.36 (PA14)
/CONTROL/SWDIO: J6.2 (SWDIO), U1.35 (PA13)
/CONTROL/USB_CC._{1}: U1.28 (PA8), U1.29 (PA9/UCPD1_DBCC1); also elsewhere on the board
/CONTROL/USB_CC._{2}: U1.27 (PB15), U1.32 (PA10/UCPD1_DBCC2); also elsewhere on the board
/CONTROL/USB_OUT.3+: U1.34 (PA12/PA10); also elsewhere on the board
/CONTROL/USB_OUT.3-: U1.33 (PA11/PA9); also elsewhere on the board
/CONTROL/USB_RST: U1.14 (PA3); also elsewhere on the board
/CONTROL/V_SENSE: R1.2, R2.1, U1.20 (PB1)
/PWR_GEN/5V: R1.1; also elsewhere on the board
GND: C1.2, C2.2, C39.2, C40.2, D14.1 (K), J2.3, J2.4, J2.5, J6.5 (GND), R2.2, R25.1, R26.1, U1.7 (VSS); also elsewhere on the board
unnamed: D14.2 (A), R22.1
unnamed: R22.2, U1.37 (PA15)
unnamed: R25.2, U1.38 (PD0)
unnamed: R26.2, U1.39 (PD1)

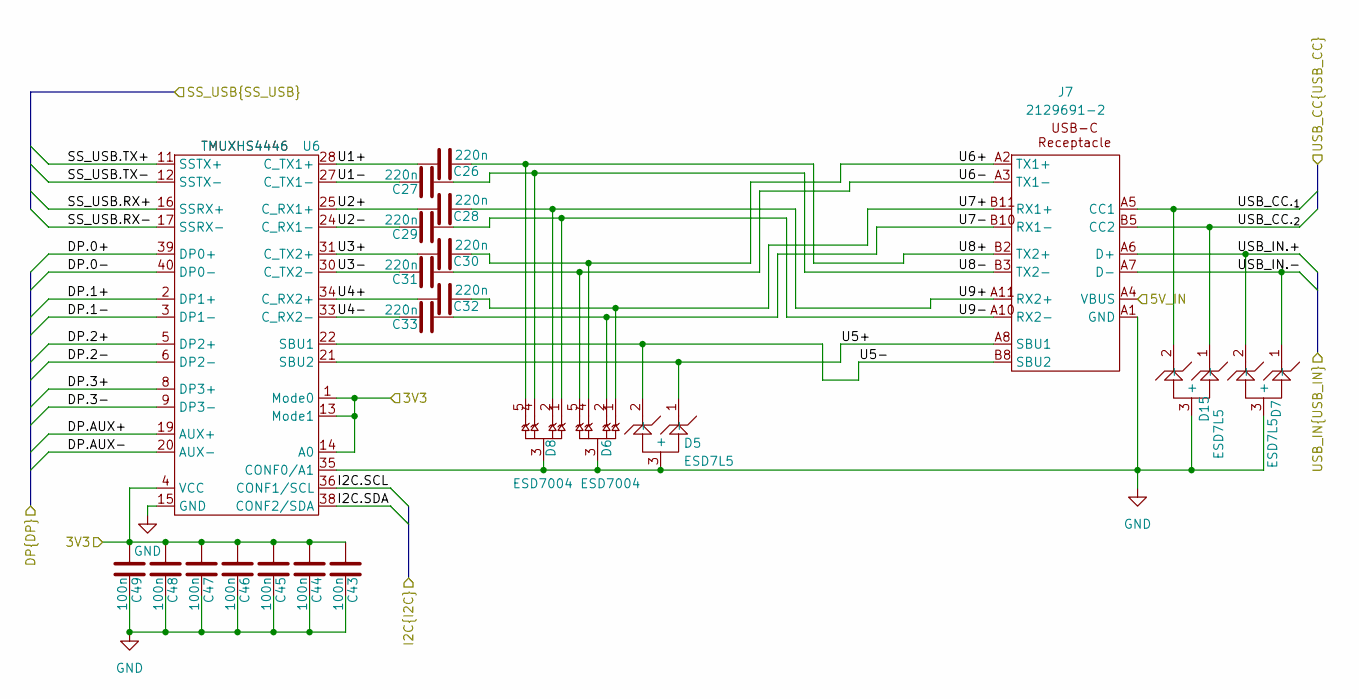
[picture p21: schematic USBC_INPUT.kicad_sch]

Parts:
C26, C27, C28, C29, C30, C31, C32, C33: 220n; 0402_C
C43, C44, C45, C46, C47, C48, C49: 100n; 0402_C
D5, D7, D15: ESD7L5
D6, D8: ESD7004
J7: 2129691-2; 2129691-2_2.8mmOut
U6: TMUXHS4446

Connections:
/CONTROL/3V3: C43.2, C44.2, C45.2, C46.2, C47.2, C48.2, C49.2, U6.1 (Mode0), U6.4 (VCC), U6.7, U6.10, U6.13 (Mode1), U6.14 (A0), U6.23, U6.26, U6.29, U6.32; also elsewhere on the board
/CONTROL/I2C.SCL: U6.36 (CONF1/SCL); also elsewhere on the board
/CONTROL/I2C.SDA: U6.38 (CONF2/SDA); also elsewhere on the board
/CONTROL/USB_CC._{1}: D15.2 (-), J7.A5 (CC1); also elsewhere on the board
/CONTROL/USB_CC._{2}: D15.1 (-), J7.B5 (CC2); also elsewhere on the board
/PWR_GEN/5V_R: J7.A4 (VBUS), J7.A9, J7.B4, J7.B9; also elsewhere on the board
/USBC_INPUT/DP.0+: U6.39 (DP0+); also elsewhere on the board
/USBC_INPUT/DP.0-: U6.40 (DP0-); also elsewhere on the board
/USBC_INPUT/DP.1+: U6.2 (DP1+); also elsewhere on the board
/USBC_INPUT/DP.1-: U6.3 (DP1-); also elsewhere on the board
/USBC_INPUT/DP.2+: U6.5 (DP2+)
/USBC_INPUT/DP.2-: U6.6 (DP2-)
/USBC_INPUT/DP.3+: U6.8 (DP3+)
/USBC_INPUT/DP.3-: U6.9 (DP3-)
/USBC_INPUT/DP.AUX+: U6.19 (AUX+); also elsewhere on the board
/USBC_INPUT/DP.AUX-: U6.20 (AUX-); also elsewhere on the board
/USBC_INPUT/SS_USB.RX+: U6.16 (SSRX+); also elsewhere on the board
/USBC_INPUT/SS_USB.RX-: U6.17 (SSRX-); also elsewhere on the board
/USBC_INPUT/SS_USB.TX+: U6.11 (SSTX+); also elsewhere on the board
/USBC_INPUT/SS_USB.TX-: U6.12 (SSTX-); also elsewhere on the board
/USBC_INPUT/U1+: C26.2, U6.28 (C_TX1+)
/USBC_INPUT/U1-: C27.2, U6.27 (C_TX1-)
/USBC_INPUT/U2+: C28.2, U6.25 (C_RX1+)
/USBC_INPUT/U2-: C29.2, U6.24 (C_RX1-)
/USBC_INPUT/U3+: C30.2, U6.31 (C_TX2+)
/USBC_INPUT/U3-: C31.2, U6.30 (C_TX2-)
/USBC_INPUT/U4+: C32.2, U6.34 (C_RX2+)
/USBC_INPUT/U4-: C33.2, U6.33 (C_RX2-)
/USBC_INPUT/U5+: D5.1 (-), J7.A8 (SBU1), U6.21 (SBU2)
/USBC_INPUT/U5-: D5.2 (-), J7.B8 (SBU2), U6.22 (SBU1)
/USBC_INPUT/U6+: C30.1, D6.4, D6.7, J7.A2 (TX1+)
/USBC_INPUT/U6-: C31.1, D6.5, D6.6, J7.A3 (TX1-)
/USBC_INPUT/U7+: C32.1, D6.1, D6.10, J7.B11 (RX1+)
/USBC_INPUT/U7-: C33.1, D6.2, D6.9, J7.B10 (RX1-)
/USBC_INPUT/U8+: C26.1, D8.5, D8.6, J7.B2 (TX2+)
/USBC_INPUT/U8-: C27.1, D8.4, D8.7, J7.B3 (TX2-)
/USBC_INPUT/U9+: C28.1, D8.2, D8.9, J7.A11 (RX2+)
/USBC_INPUT/U9-: C29.1, D8.1, D8.10, J7.A10 (RX2-)
/USBC_INPUT/USB_IN.+: D7.2 (-), J7.A6 (D+), J7.B6; also elsewhere on the board
/USBC_INPUT/USB_IN.-: D7.1 (-), J7.A7 (D-), J7.B7; also elsewhere on the board
GND: C43.1, C44.1, C45.1, C46.1, C47.1, C48.1, C49.1, D5.3 (+), D6.3, D6.8, D7.3 (+), D8.3, D8.8, D15.3 (+), J7.A1 (GND), J7.A12, J7.B1, J7.B12, J7.S, U6.15 (GND), U6.18, U6.35 (CONF0/A1), U6.37, U6.41; also elsewhere on the board

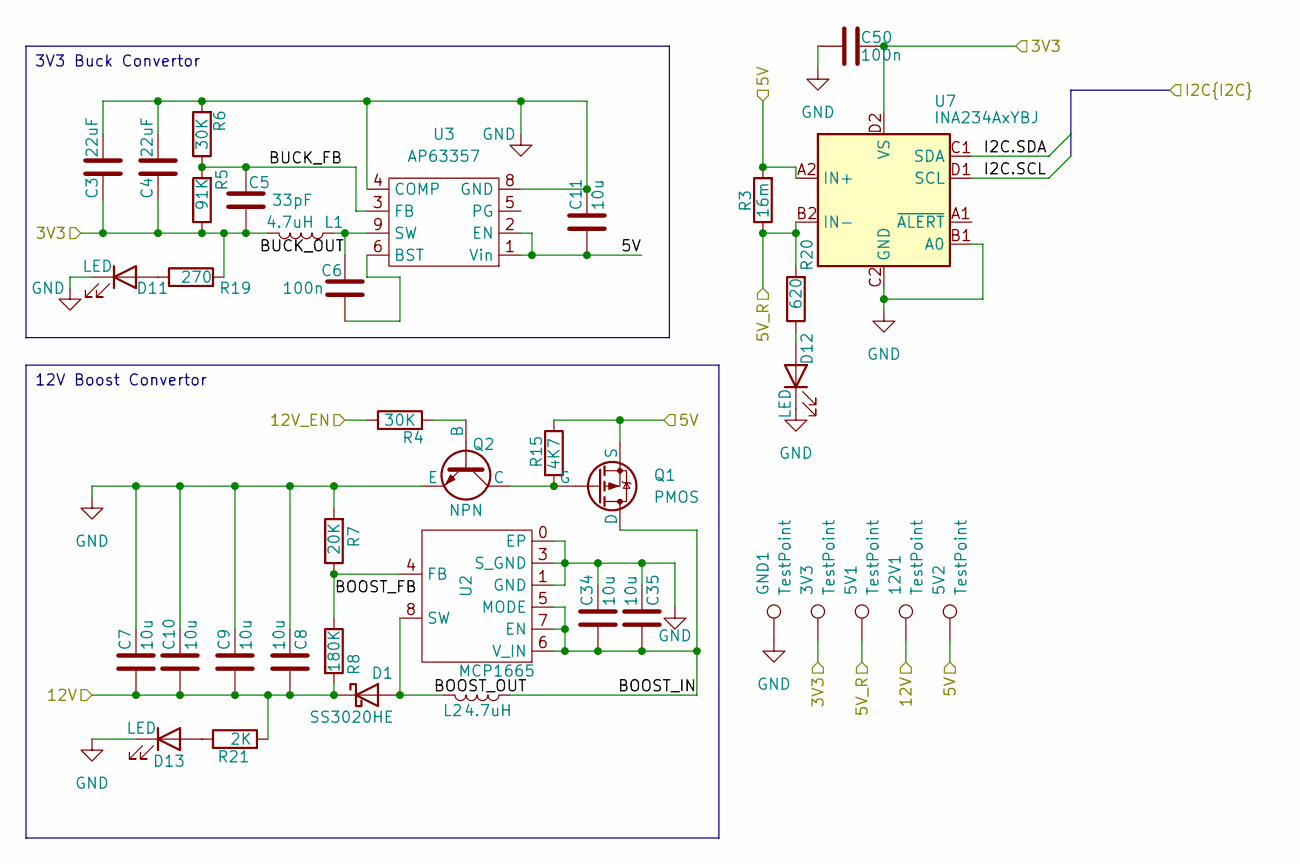
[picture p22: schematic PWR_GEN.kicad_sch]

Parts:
3V3, 5V1, 5V2, 12V1: TestPoint; TestPoint_Pad_D1.0mm
C3, C4: 22uF; 0603_C
C5: 33pF; 0603_C
C6: 100n; 0603_C
C7, C8, C9, C10, C11, C34, C35: 10u; 0603_C
C50: 100n; 0402_C
D1: SS3020HE
D11, D12, D13: LED; LTST_Diode
GND1: TestPoint; TestPoint_Pad_D1.0mm
L1, L2: 4.7uH; XGL4018_Inductor
Q1: PMOS; TSOT-23
Q2: NPN; TSOT-23
R3: 16m; 0612_R_v2
R4, R6: 30K; 0603_R
R5: 91K; 0603_R
R7: 20K; 0603_R
R8: 180K; 0603_R
R15: 4K7; 0603_R
R19: 270; 0603_R
R20: 620; 0603_R
R21: 2K; 0603_R
U2: MCP1665
U3: AP63357
U7: INA234AxYBJ; INA234

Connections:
/CONTROL/3V3: 3V3.1, C3.1, C4.1, C5.2, C50.1, L1.2, R5.1, R19.2, U7.D2 (VS); also elsewhere on the board
/CONTROL/BL_ENABLE: R4.1; also elsewhere on the board
/CONTROL/I2C.SCL: U7.D1 (SCL); also elsewhere on the board
/CONTROL/I2C.SDA: U7.C1 (SDA); also elsewhere on the board
/PWR_GEN/5V: 5V2.1, C11.2, Q1.2 (S), R3.2, R15.1, U3.1 (Vin), U3.2 (EN), U7.A2 (IN+); also elsewhere on the board
/PWR_GEN/5V_R: 5V1.1, R3.1, R20.2, U7.B2 (IN-); also elsewhere on the board
/PWR_GEN/12V: 12V1.1, C7.2, C8.2, C9.2, C10.2, D1.1 (K), R8.2, R21.2; also elsewhere on the board
/PWR_GEN/BOOST_FB: R7.1, R8.1, U2.4 (FB)
/PWR_GEN/BOOST_IN: C34.2, C35.2, L2.1, Q1.3 (D), U2.5 (MODE), U2.6 (V_IN), U2.7 (EN)
/PWR_GEN/BOOST_OUT: D1.2 (A), L2.2, U2.8 (SW), U2.9
/PWR_GEN/BUCK_FB: C5.1, R5.2, R6.1, U3.3 (FB)
/PWR_GEN/BUCK_OUT: C6.2, L1.1, U3.7 (NC), U3.9 (SW)
GND: C3.2, C4.2, C7.1, C8.1, C9.1, C10.1, C11.1, C34.1, C35.1, C50.2, D11.1 (K), D12.1 (K), D13.1 (K), GND1.1, Q2.2 (E), R6.2, R7.2, U2.0 (EP), U2.1 (GND), U2.2, U2.3 (S_GND), U2.10, U3.4 (COMP), U3.8 (GND), U7.B1 (A0), U7.C2 (GND); also elsewhere on the board
unnamed: D11.2 (A), R19.1
unnamed: D12.2 (A), R20.1
unnamed: D13.2 (A), R21.1
unnamed: Q1.1 (G), Q2.3 (C), R15.2
unnamed: Q2.1 (B), R4.2
unnamed: C6.1, U3.6 (BST)

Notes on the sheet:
12V Boost Convertor
3V3 Buck Convertor

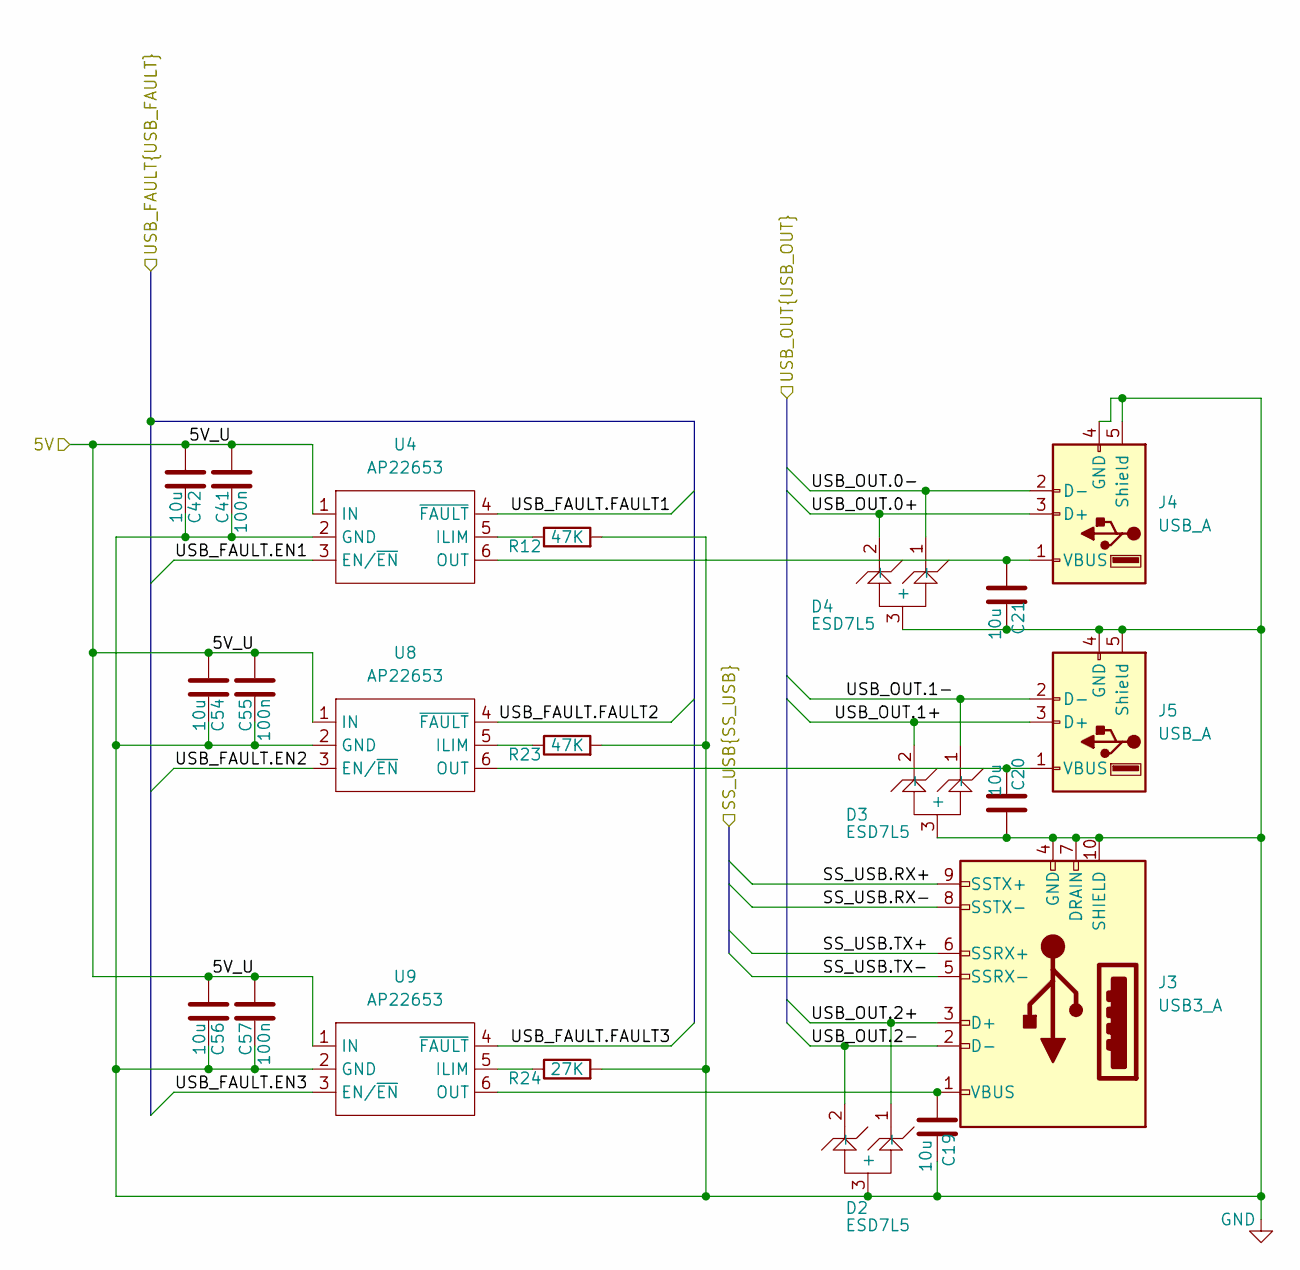
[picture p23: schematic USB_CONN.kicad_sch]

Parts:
C19, C20, C21, C42, C54, C56: 10u; 0603_C
C41, C55, C57: 100n; 0603_C
D2, D3, D4: ESD7L5
J3: USB3_A; USBA32_692121230100v2_1.6mmOut
J4, J5: USB_A; USB1015v2_1.6mmOut
R12, R23: 47K; 0603_R
R24: 27K; 0603_R
U4, U8, U9: AP22653; AP22652-DFN

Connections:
/CONTROL/USB_OUT.0+: D4.2 (-), J4.3 (D+); also elsewhere on the board
/CONTROL/USB_OUT.0-: D4.1 (-), J4.2 (D-); also elsewhere on the board
/CONTROL/USB_OUT.1+: D3.2 (-), J5.3 (D+); also elsewhere on the board
/CONTROL/USB_OUT.1-: D3.1 (-), J5.2 (D-); also elsewhere on the board
/CONTROL/USB_OUT.2+: D2.1 (-), J3.3 (D+); also elsewhere on the board
/CONTROL/USB_OUT.2-: D2.2 (-), J3.2 (D-); also elsewhere on the board
/PWR_GEN/5V: C41.1, C42.1, C54.1, C55.1, C56.1, C57.1, U4.1 (IN), U8.1 (IN), U9.1 (IN); also elsewhere on the board
/USBC_INPUT/SS_USB.RX+: J3.9 (SSTX+); also elsewhere on the board
/USBC_INPUT/SS_USB.RX-: J3.8 (SSTX-); also elsewhere on the board
/USBC_INPUT/SS_USB.TX+: J3.6 (SSRX+); also elsewhere on the board
/USBC_INPUT/SS_USB.TX-: J3.5 (SSRX-); also elsewhere on the board
/USB_CONN/USB_FAULT.EN1: U4.3 (EN/~EN); also elsewhere on the board
/USB_CONN/USB_FAULT.EN2: U8.3 (EN/~EN); also elsewhere on the board
/USB_CONN/USB_FAULT.EN3: U9.3 (EN/~EN); also elsewhere on the board
/USB_CONN/USB_FAULT.FAULT1: U4.4 (~FAULT); also elsewhere on the board
/USB_CONN/USB_FAULT.FAULT2: U8.4 (~FAULT); also elsewhere on the board
/USB_CONN/USB_FAULT.FAULT3: U9.4 (~FAULT); also elsewhere on the board
GND: C19.2, C20.2, C21.2, C41.2, C42.2, C54.2, C55.2, C56.2, C57.2, D2.3 (+), D3.3 (+), D4.3 (+), J3.4 (GND), J3.7 (DRAIN), J3.10 (SHIELD), J4.4 (GND), J4.5 (Shield), J5.4 (GND), J5.5 (Shield), R12.2, R23.2, R24.2, U4.2 (GND), U4.S, U8.2 (GND), U8.S, U9.2 (GND), U9.S; also elsewhere on the board
unnamed: C19.1, J3.1 (VBUS), U9.6 (OUT)
unnamed: C21.1, J4.1 (VBUS), U4.6 (OUT)
unnamed: C20.1, J5.1 (VBUS), U8.6 (OUT)
unnamed: R12.1, U4.5 (ILIM)
unnamed: R23.1, U8.5 (ILIM)
unnamed: R24.1, U9.5 (ILIM)

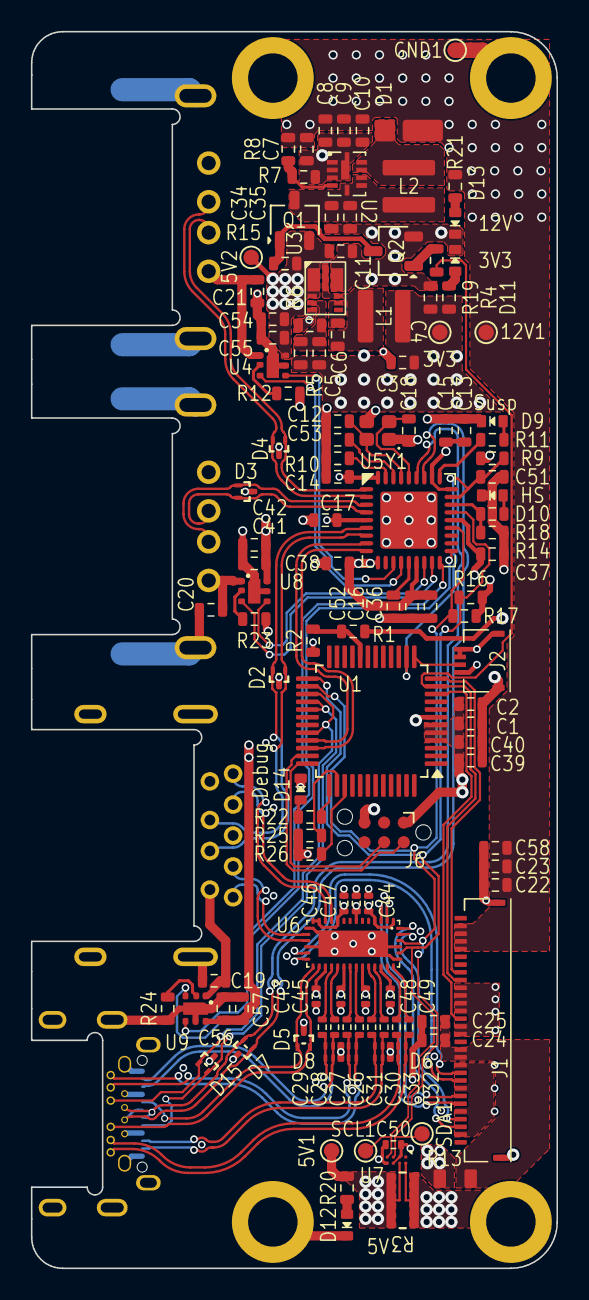
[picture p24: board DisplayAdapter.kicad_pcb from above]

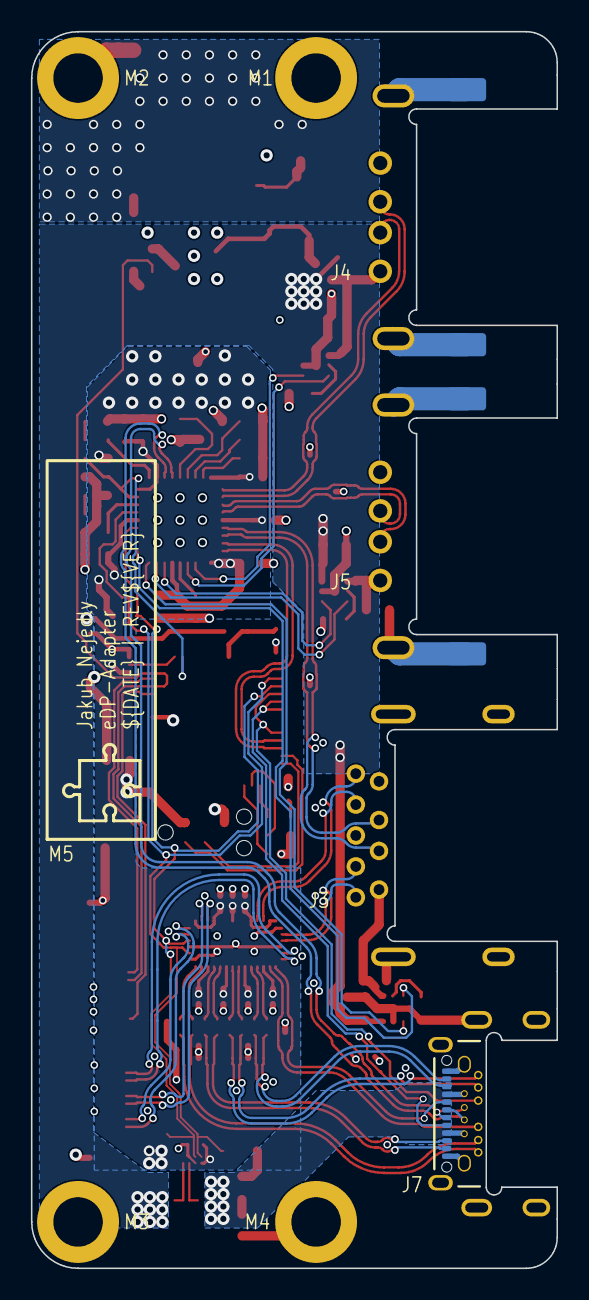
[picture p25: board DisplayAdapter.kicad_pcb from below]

Board: 4 copper layers, 34.0 x 80.0 mm, 132 parts (9 on the bottom side), 92 nets.

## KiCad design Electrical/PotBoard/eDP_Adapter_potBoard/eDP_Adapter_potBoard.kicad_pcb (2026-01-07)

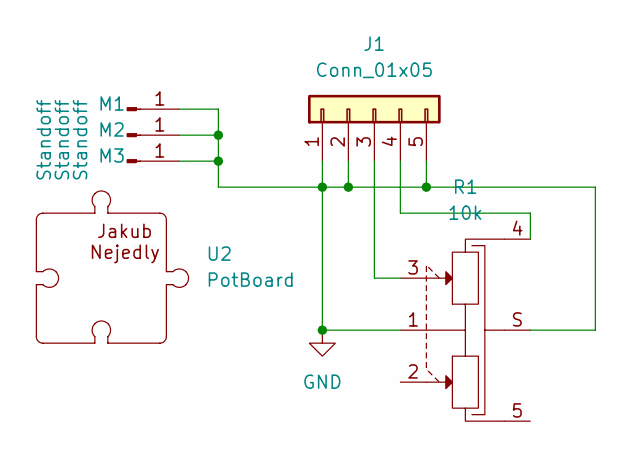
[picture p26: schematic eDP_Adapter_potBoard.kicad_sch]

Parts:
J1: Conn_01x05; FH19C-4S-0.5SH(10)
M1, M2, M3: Standoff; MS04-M2-2
R1: 10k; RK10J12R0A0B
U2: PotBoard; Logo_SMALL

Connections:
GND: J1.1, J1.2, J1.5, M1.1, M2.1, M3.1, R1.1, R1.S
unnamed: J1.3, R1.3
unnamed: J1.4, R1.4

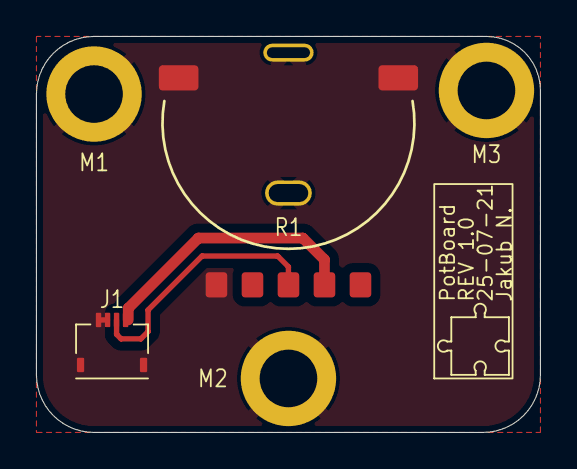
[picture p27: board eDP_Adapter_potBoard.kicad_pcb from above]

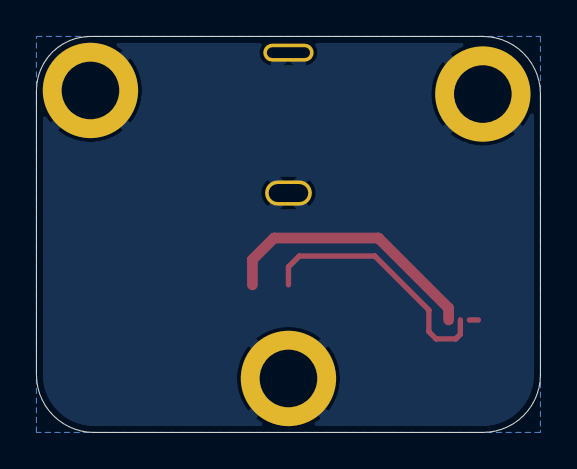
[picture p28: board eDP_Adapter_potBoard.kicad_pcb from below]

Board: 2 copper layers, 28.0 x 22.0 mm, 6 parts (3 on the bottom side), 3 nets.

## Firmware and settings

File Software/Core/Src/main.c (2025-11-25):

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
/* Includes ------------------------------------------------------------------*/
#include "main.h"
#include "cmsis_os.h"
#include "usbpd.h"

/* USER CODE BEGIN Includes */
#include "eDP_adapt.h"

/* USER CODE END Includes */

ADC_HandleTypeDef hadc1;
DMA_HandleTypeDef hdma_adc1;

I2C_HandleTypeDef hi2c2;

TIM_HandleTypeDef htim2;

/* Definitions for defaultTask */
osThreadId_t defaultTaskHandle;
const osThreadAttr_t defaultTask_attributes = {
  .name = "defaultTask",
  .priority = (osPriority_t) osPriorityNormal,
  .stack_size = 128 * 4
};
void SystemClock_Config(void);
static void MX_GPIO_Init(void);
static void MX_DMA_Init(void);
static void MX_ADC1_Init(void);
static void MX_UCPD1_Init(void);
static void MX_TIM2_Init(void);
static void MX_I2C2_Init(void);
void StartDefaultTask(void *argument);

/**
  * @brief  The application entry point.
  * @retval int
  */
int main(void)
{

  /* MCU Configuration--------------------------------------------------------*/

  /* Reset of all peripherals, Initializes the Flash interface and the Systick. */
  HAL_Init();

  /* Configure the system clock */
  SystemClock_Config();

  /* Initialize all configured peripherals */
  MX_GPIO_Init();
  MX_DMA_Init();
  MX_ADC1_Init();
  MX_UCPD1_Init();
  MX_TIM2_Init();
  MX_I2C2_Init();
  /* Init scheduler */
  osKernelInitialize();
  /* USBPD initialisation ---------------------------------*/
  MX_USBPD_Init();

  /* USER CODE BEGIN RTOS_MUTEX */
  /* add mutexes, ... */
  /* USER CODE END RTOS_MUTEX */

  /* USER CODE BEGIN RTOS_SEMAPHORES */
  /* add semaphores, ... */
  /* USER CODE END RTOS_SEMAPHORES */

  /* USER CODE BEGIN RTOS_TIMERS */
  /* start timers, add new ones, ... */
  /* USER CODE END RTOS_TIMERS */

  /* USER CODE BEGIN RTOS_QUEUES */
  /* add queues, ... */
  /* USER CODE END RTOS_QUEUES */

  /* Create the thread(s) */
  /* creation of defaultTask */
  defaultTaskHandle = osThreadNew(StartDefaultTask, NULL, &defaultTask_attributes);

  /* USER CODE BEGIN RTOS_THREADS */
  /* add threads, ... */
  /* USER CODE END RTOS_THREADS */

  /* USER CODE BEGIN RTOS_EVENTS */
  /* add events, ... */
  /* USER CODE END RTOS_EVENTS */

  /* Start scheduler */
  osKernelStart();

  /* We should never get here as control is now taken by the scheduler */

  /* Infinite loop */
  /* USER CODE BEGIN WHILE */
  while (1)
  {
    /* USER CODE END WHILE */

    /* USER CODE BEGIN 3 */
  }
  /* USER CODE END 3 */
}

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
/* USER CODE BEGIN Header_StartDefaultTask */
/**
  * @brief  Function implementing the defaultTask thread.
  * @param  argument: Not used
  * @retval None
  */
/* USER CODE END Header_StartDefaultTask */
void StartDefaultTask(void *argument)
{
  /* USER CODE BEGIN 5 */
	initTask();
  /* Infinite loop */

  for(;;)
  {
	mainLoop();
  }
  /* USER CODE END 5 */
}

/**
  * @brief  This function is executed in case of error occurrence.
  * @retval None
  */
void Error_Handler(void)
{
  /* USER CODE BEGIN Error_Handler_Debug */
  /* User can add his own implementation to report the HAL error return state */
  __disable_irq();
  while (1)
  {
  }
  /* USER CODE END Error_Handler_Debug */
}
#ifdef USE_FULL_ASSERT
/**
  * @brief  Reports the name of the source file and the source line number
  *         where the assert_param error has occurred.
  * @param  file: pointer to the source file name
  * @param  line: assert_param error line source number
  * @retval None
  */
void assert_failed(uint8_t *file, uint32_t line)
{
  /* USER CODE BEGIN 6 */
  /* User can add his own implementation to report the file name and line number,
     ex: printf("Wrong parameters value: file %s on line %d\r\n", file, line) */
  /* USER CODE END 6 */
}
#endif /* USE_FULL_ASSERT */

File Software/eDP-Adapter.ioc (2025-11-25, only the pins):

Mcu.UserName=STM32G0B1CETx
PA0.GPIO_Label=BL_Enable
PA0.Signal=GPIO_Output
PA1.GPIO_Label=BL_PWM
PA1.Signal=S_TIM2_CH2
PA10.Signal=UCPD1_DBCC2
PA13.Signal=SYS_SWDIO
PA14-BOOT0.Signal=SYS_SWCLK
PA15.GPIO_Label=DEBUG
PA15.Signal=GPIO_Output
PA2.GPIO_Label=BL_Sense
PA2.Signal=ADC1_IN2
PA8.Signal=UCPD1_CC1
PA9.Signal=UCPD1_DBCC1
PB1.GPIO_Label=V_Sense
PB1.Signal=ADC1_IN9
PB13.Signal=I2C2_SCL
PB14.Signal=I2C2_SDA
PB15.Signal=UCPD1_CC2
PD0.GPIO_Label=VER0
PD0.Signal=GPIO_Input
PD1.GPIO_Label=VER1
PD1.Signal=GPIO_Input

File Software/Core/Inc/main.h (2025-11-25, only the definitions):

#define VDDA_APPLI 3300
#define BL_Enable_Pin GPIO_PIN_0
#define BL_Enable_GPIO_Port GPIOA
#define BL_PWM_Pin GPIO_PIN_1
#define BL_PWM_GPIO_Port GPIOA
#define BL_Sense_Pin GPIO_PIN_2
#define BL_Sense_GPIO_Port GPIOA
#define V_Sense_Pin GPIO_PIN_1
#define V_Sense_GPIO_Port GPIOB
#define DEBUG_Pin GPIO_PIN_15
#define DEBUG_GPIO_Port GPIOA
#define VER0_Pin GPIO_PIN_0
#define VER0_GPIO_Port GPIOD
#define VER1_Pin GPIO_PIN_1
#define VER1_GPIO_Port GPIOD

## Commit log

2025-11-25 Added Functional Branch of the Software
    [eDP-Adapter Debug.cfg]
2025-11-25 Imported Electrical Hardware
    [CONTROL.kicad_sch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]
2026-01-07 Fixed Font issues
    [DisplayAdapter.kicad_pcb]
2026-01-07 BOM and fixed potboard font
    [DisplayAdapter.csv, eDP_Adapter_potBoard.kicad_pcb, eDP_Adapter_potBoard.kicad_sch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]
2026-01-07 Added Mechanical components, fixed electrical err
    [Back.3MF, Back.SLDPRT, Bot_Bezel.3MF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]

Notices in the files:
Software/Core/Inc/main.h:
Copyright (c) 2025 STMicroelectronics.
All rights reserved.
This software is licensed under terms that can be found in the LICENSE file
